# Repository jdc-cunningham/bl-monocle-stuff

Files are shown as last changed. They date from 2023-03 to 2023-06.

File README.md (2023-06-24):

### Desk stand for recording with phone

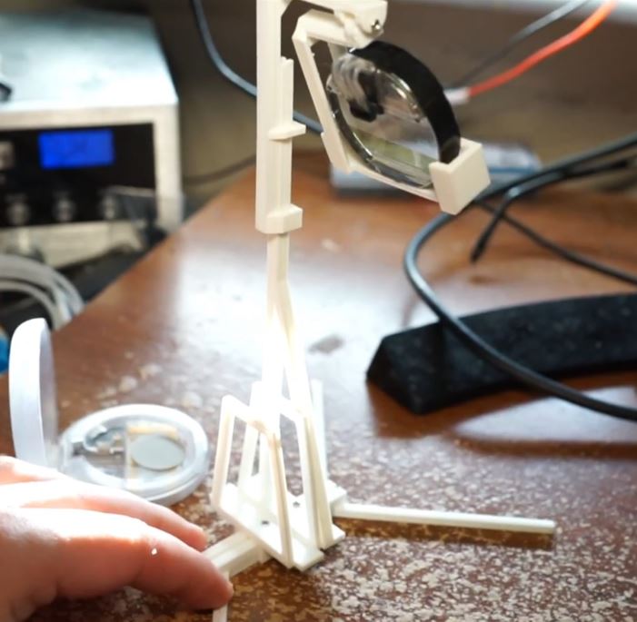
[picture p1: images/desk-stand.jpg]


This is designed to be dynamic for the most part (can fit different phones) with sliding adjustments

<a href="https://www.youtube.com/watch?v=oRKQFbEJR7w">View video (YouTube)</a>

### Hand held stand

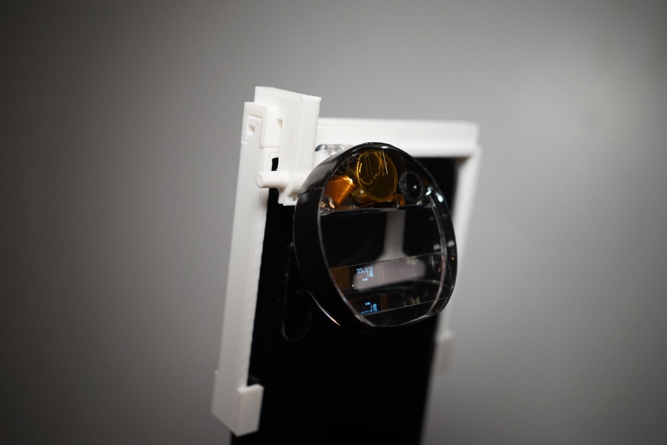
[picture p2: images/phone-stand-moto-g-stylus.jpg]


While this is custom designed for this phone (and one for iPhone 14 pro max), the concept is the same for other phones.

The simple design below can be used as a base regarding the paddle/rotating mechanism.

<a href="https://www.youtube.com/watch?v=hVtDwkcApw0">View video (YouTube)</a>

### "Popsicle stick" stand

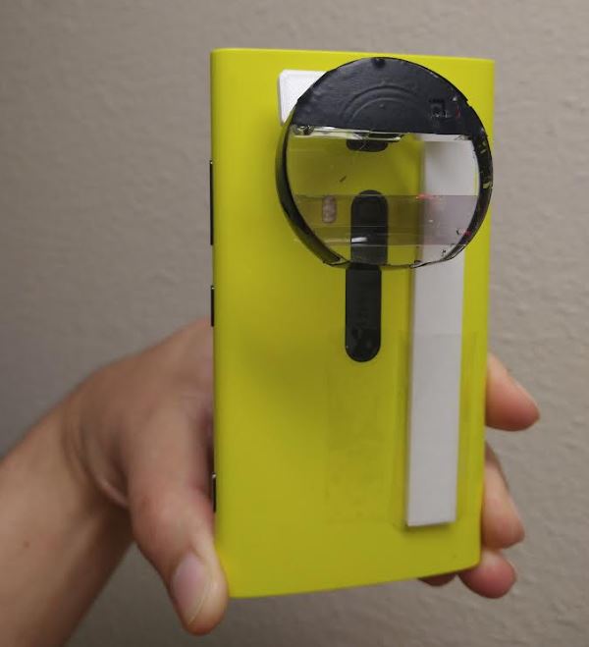
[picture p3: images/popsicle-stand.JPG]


This one is the simplest/fastest to print. It's nice because it be used for pretty much any phone. You can see here that I temporarily taped it to the phone.

### Permanent clip

This is a sign of madness

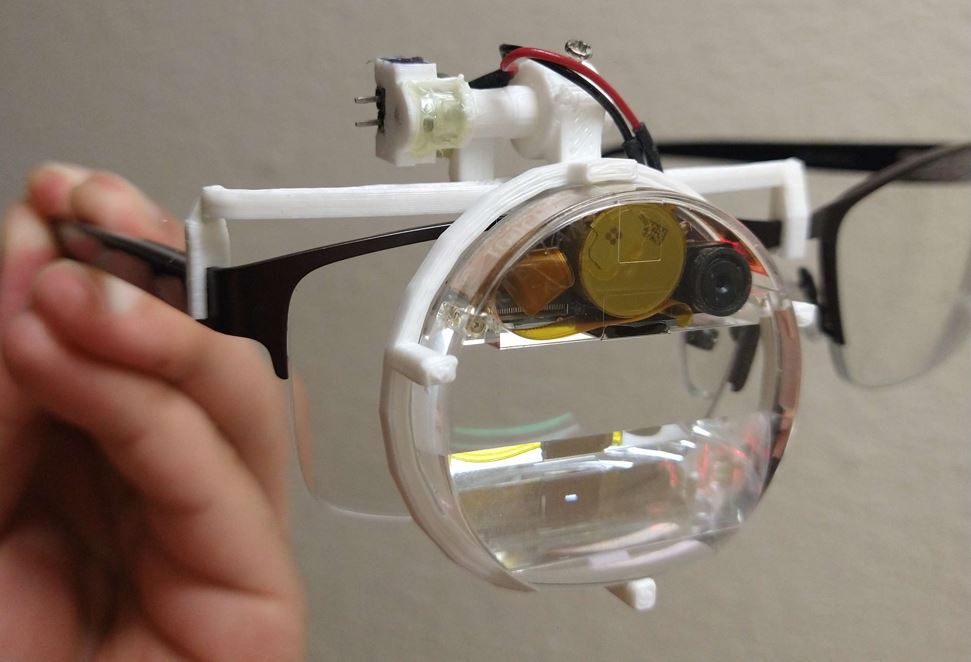
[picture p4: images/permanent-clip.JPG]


The point of this was so that I wouldn't have to take the monocle out of the case/position it over my eye just right every time I used it... During the process of prototyping many (~30) of these clips, I snapped the clip off. So I had to print the ring thing to hold it... anyway positive is I brought the image up/eye level vs. looking down (original) but the text is blurrier/farthest near corner text has doubling, redish tint in some areas near middle. It has a janky magnetic charger too.

Would I recommend? no

### Detachable clip (mod of above)

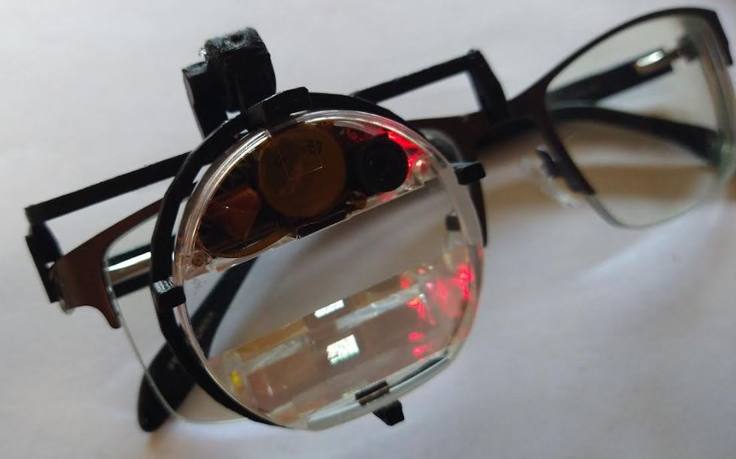
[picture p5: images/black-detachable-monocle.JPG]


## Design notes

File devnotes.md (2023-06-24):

06/24/2023

8:09 AM

just killing time, at this point I've switched to black fillament which is convenient, that looks better

I decided to not use the magnetic charging thing anymore, since the monocle does stop working after several hours of being on

Aside from that, it takes away from the original design where it was this thing that sits in a case/charges and you pull it out when needed

I unfortunately broke my clip off so that's why I'm using the clip design on my spare glasses

I did remove the soldered wires to the pogo contacts so it can go back into the case

The monocle no longer stays on as long as it can/back to normal use

I'm working on improving the clip design since it currently can fall out of the socket thing (monocle ring mount)

At least these are quick to print/try out and I have time to kill today

8:49 AM

the black filament looks good, more discrete

11:38 AM

the frame could be angled downwards more but I can compensate with "glue" (shudders) on the connection points, it looks great though in black

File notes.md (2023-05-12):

### Display text sizing

Currently can fit 26 across, 8 vertically eg. 8x26

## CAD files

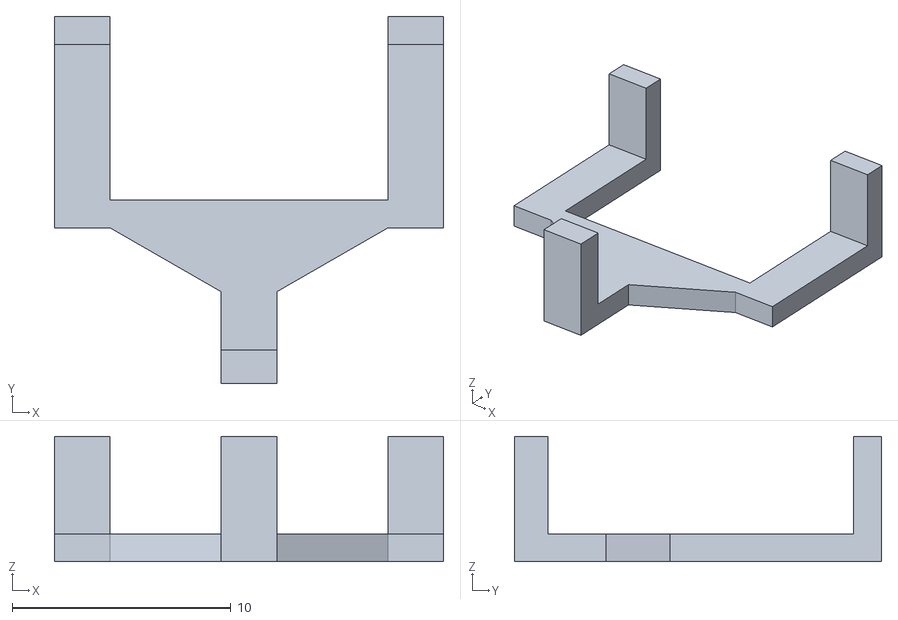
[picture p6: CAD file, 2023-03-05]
3d-printing/glasses-base-clip/base-clip.stl
17.8 x 16.8 x 5.72

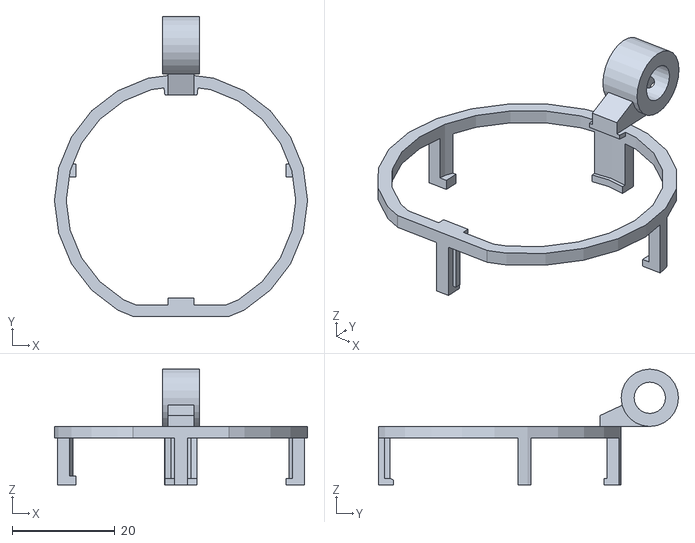
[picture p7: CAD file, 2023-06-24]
3d-printing/glasses-detachable-clip/monocle-ring-mount.stl
49.3 x 58.4 x 22.6

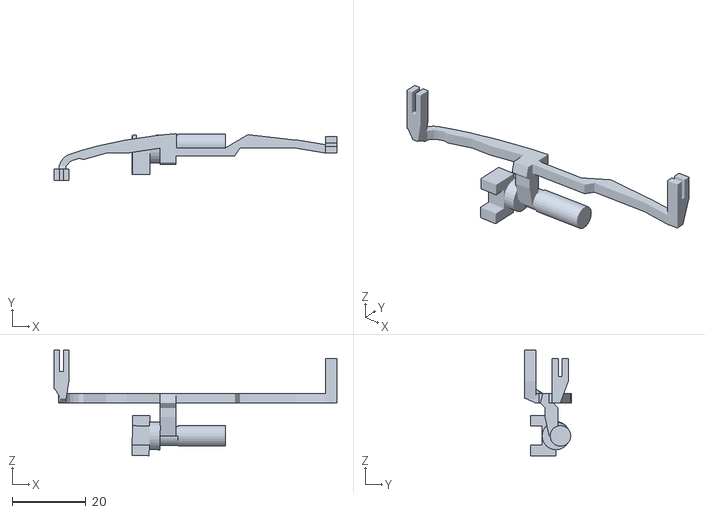
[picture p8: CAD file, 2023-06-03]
3d-printing/glasses-permanent-clip/clip.stl
76.6 x 12.6 x 28.6

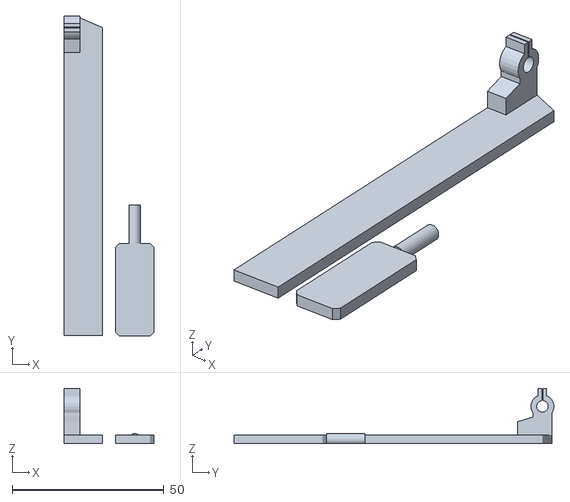
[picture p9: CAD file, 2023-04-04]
3d-printing/iphone-14-pro-max-pop-stick-mount/stick-and-roll-paddle.stl
29.7 x 105.5 x 18.2

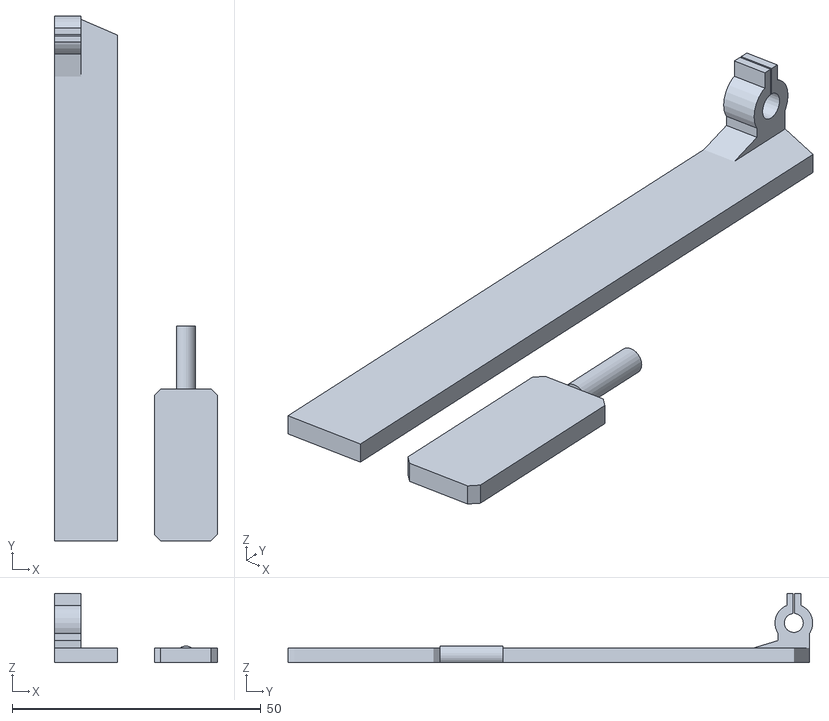
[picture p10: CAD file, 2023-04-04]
3d-printing/near-flat-cam-pop-stick-mount/pop-stick-mount.stl
32.8 x 105.4 x 13.9

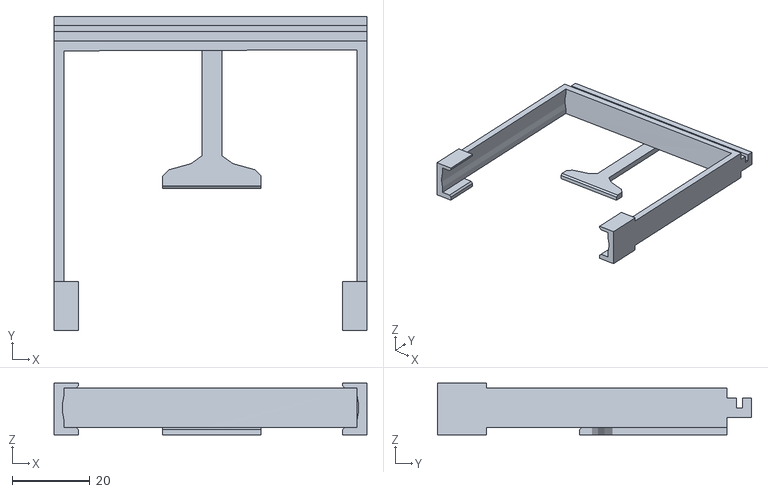
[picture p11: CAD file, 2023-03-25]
3d-printing/phone-hand-held-monocle-mount/stls/phone-clip-base.stl
80.7 x 81.0 x 13.3

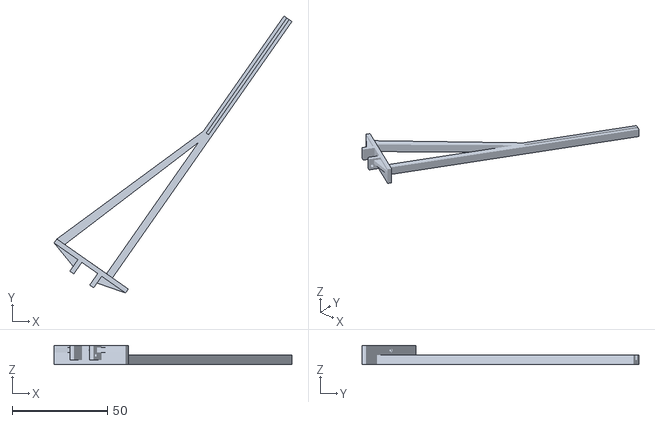
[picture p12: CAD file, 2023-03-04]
3d-printing/phone-recording-stand/stls/monocle-stand--hanger-sliding-shorter.stl
124.6 x 145.1 x 10.2

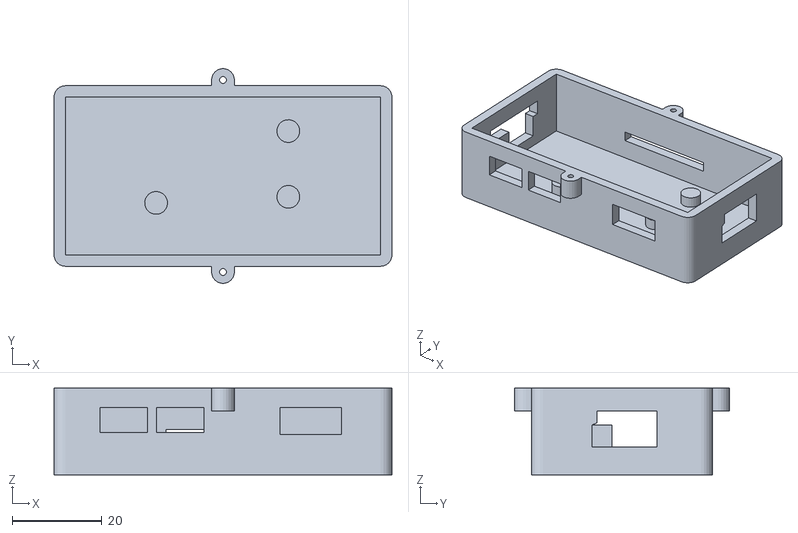
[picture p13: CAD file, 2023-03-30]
3d-printing/simone-pi-zero-case/print/pz-batt-case--bottom.stl
75.2 x 47.8 x 19.3

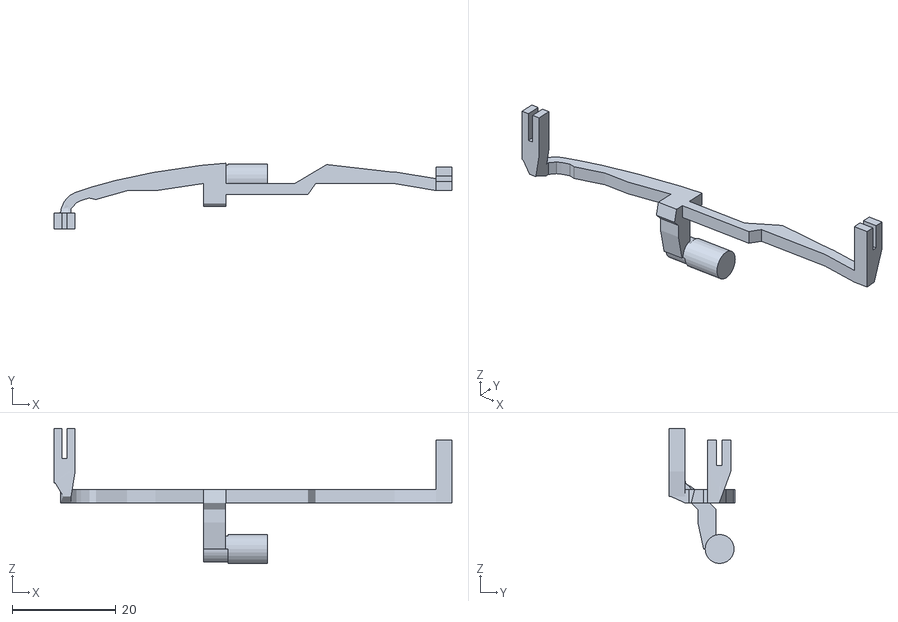
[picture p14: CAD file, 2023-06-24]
3d-printing/glasses-detachable-clip/clip.stl
76.6 x 12.6 x 26.0

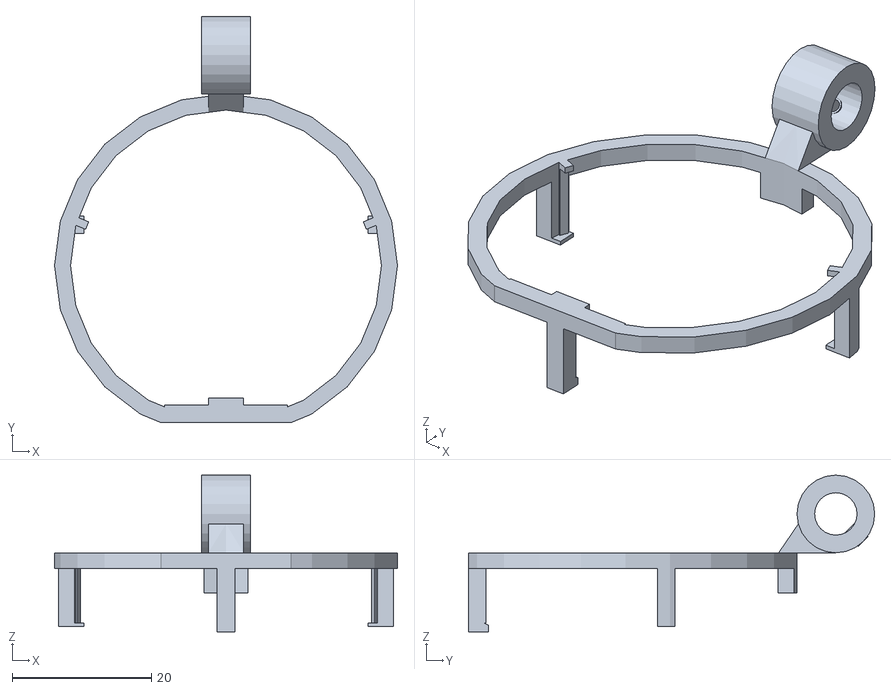
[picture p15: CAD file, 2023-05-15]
3d-printing/glasses-permanent-clip/monocle-ring-mount.stl
49.3 x 58.4 x 22.6

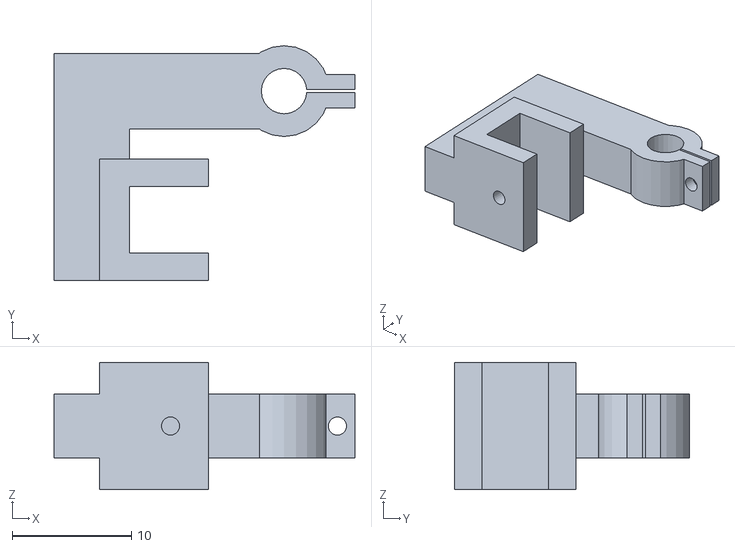
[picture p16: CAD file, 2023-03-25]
3d-printing/phone-hand-held-monocle-mount/stls/sliding-pincher.stl
25.3 x 19.7 x 10.7

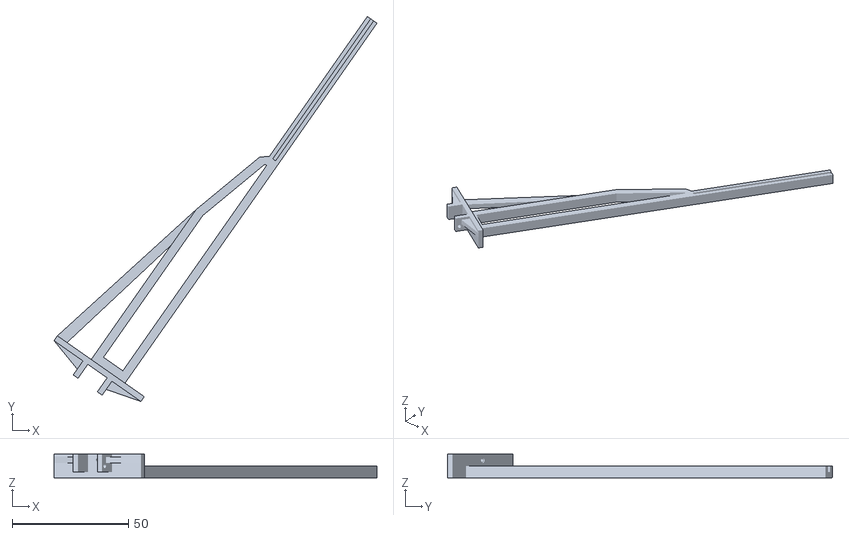
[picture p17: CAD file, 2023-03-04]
3d-printing/phone-recording-stand/stls/monocle-stand--hanger-sliding.stl
139.2 x 165.9 x 10.2

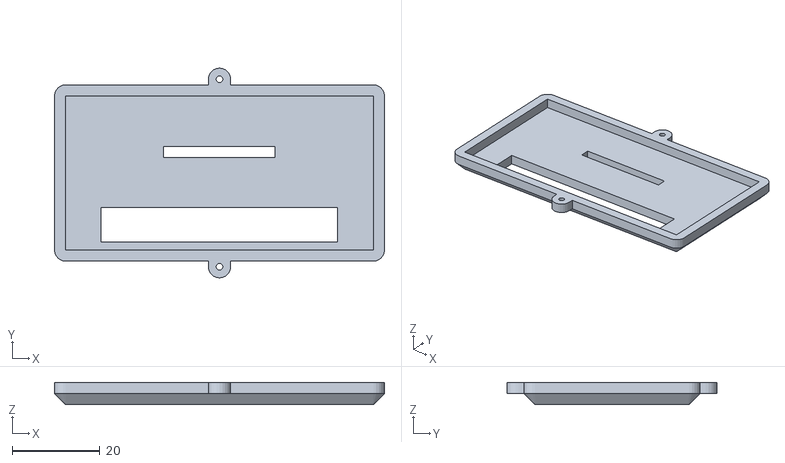
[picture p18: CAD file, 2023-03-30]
3d-printing/simone-pi-zero-case/print/pz-batt-case--top.stl
75.2 x 47.8 x 5.08

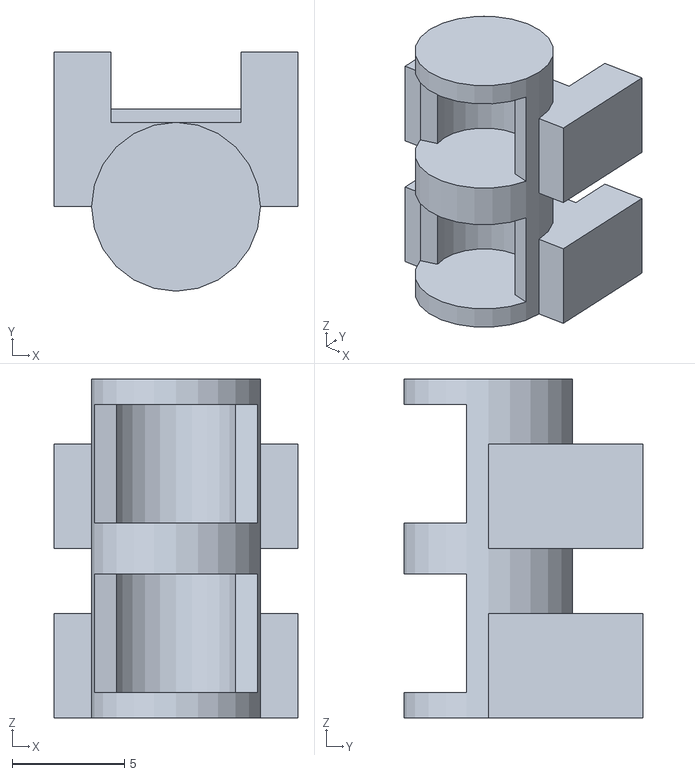
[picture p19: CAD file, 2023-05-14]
3d-printing/glasses-permanent-clip/Untitled-646140bf.stl
10.9 x 10.7 x 15.1

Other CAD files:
3d-printing/phone-hand-held-monocle-mount/stls/rotating-paddle.stl
3d-printing/phone-recording-stand/stls/monocle-sliding-pivot-mount.stl
3d-printing/simone-pi-zero-case/print/pz-batt-case--both.stl
3d-printing/glasses-permanent-clip/test-magnet-holder.stl
3d-printing/glasses-base-clip/base-clip.skp
3d-printing/glasses-detachable-clip/clip.skp
3d-printing/glasses-detachable-clip/monocle-ring-mount.skp
3d-printing/glasses-permanent-clip/2-pin-male-header.skp
3d-printing/glasses-permanent-clip/clip-0.skp
3d-printing/glasses-permanent-clip/clip-copy.skp
3d-printing/glasses-permanent-clip/clip.skp
3d-printing/glasses-permanent-clip/magnet-model.skp
3d-printing/glasses-permanent-clip/monocle-ring-mount.skp
3d-printing/glasses-permanent-clip/plug.skp
3d-printing/iphone-14-pro-max-pop-stick-mount/stick-and-roll-paddle.skp
3d-printing/models/monocle-mock.skp
3d-printing/models/moto-g.skp
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

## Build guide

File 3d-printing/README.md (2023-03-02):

### 3D Printing

The units are in inches

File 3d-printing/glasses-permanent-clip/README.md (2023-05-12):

### About

This one is so that I don't have to take the monocle out of the case/attach/reposition it on the monocle. Currently I don't take the monocle outside/just use it indoors when I cook food/wait for an hour every night.

So I'm going to make this work... then the monocle will just remain attached to my glasses in such a way that I can close the glasses arms and rest it on a thing and it'll charge.

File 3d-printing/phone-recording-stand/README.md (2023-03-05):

### Phone Recording Stand



The monocle is really hard to film IMO. It is best IMO to film it with your phone's macro feature.

So this is a stand that holds your phone upright/right against the monocle viewing area.

So you can record the monocle's display as you program it wirelessly via say the web repl.

Print times

- base 2hrs
- phone holder 40 mins
- hangar stand 1hr 47 mins
- monocle holder 1hr 9 mins
- video hangar 2 hrs (differnet height, vertically stacked cameras)

This stand was designed around 2020 Moto G Stylus

Using M1.7*6 screws

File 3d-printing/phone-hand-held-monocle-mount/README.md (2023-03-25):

### About



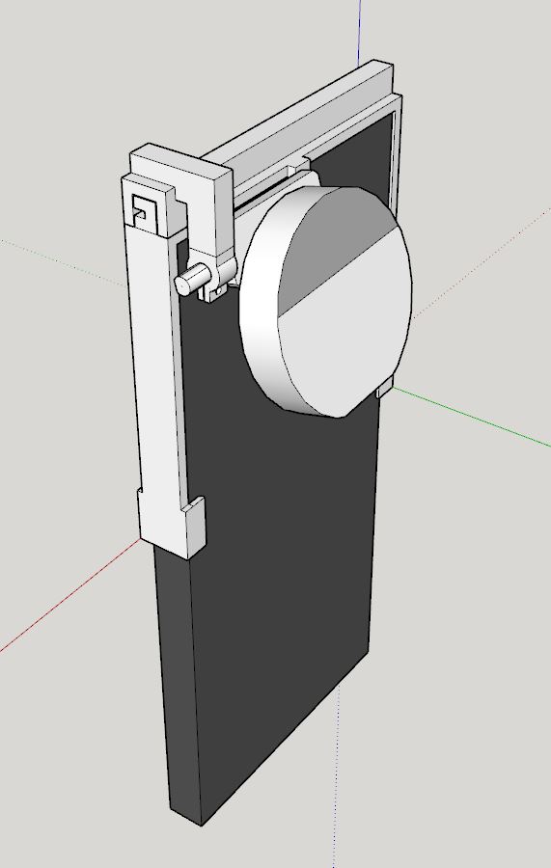
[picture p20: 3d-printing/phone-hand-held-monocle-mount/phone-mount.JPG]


This is a monocle stand that slides over your phone and allows you to record through the monocle as if being worn by an eye... specifically this one is mobile, it's not designed to be sat on a desk.

So if you want to record say an AR workflow with the monocle, you can use this.

Unfortunately phone designs vary and this one was designed around a Moto G although it has adjustable features.

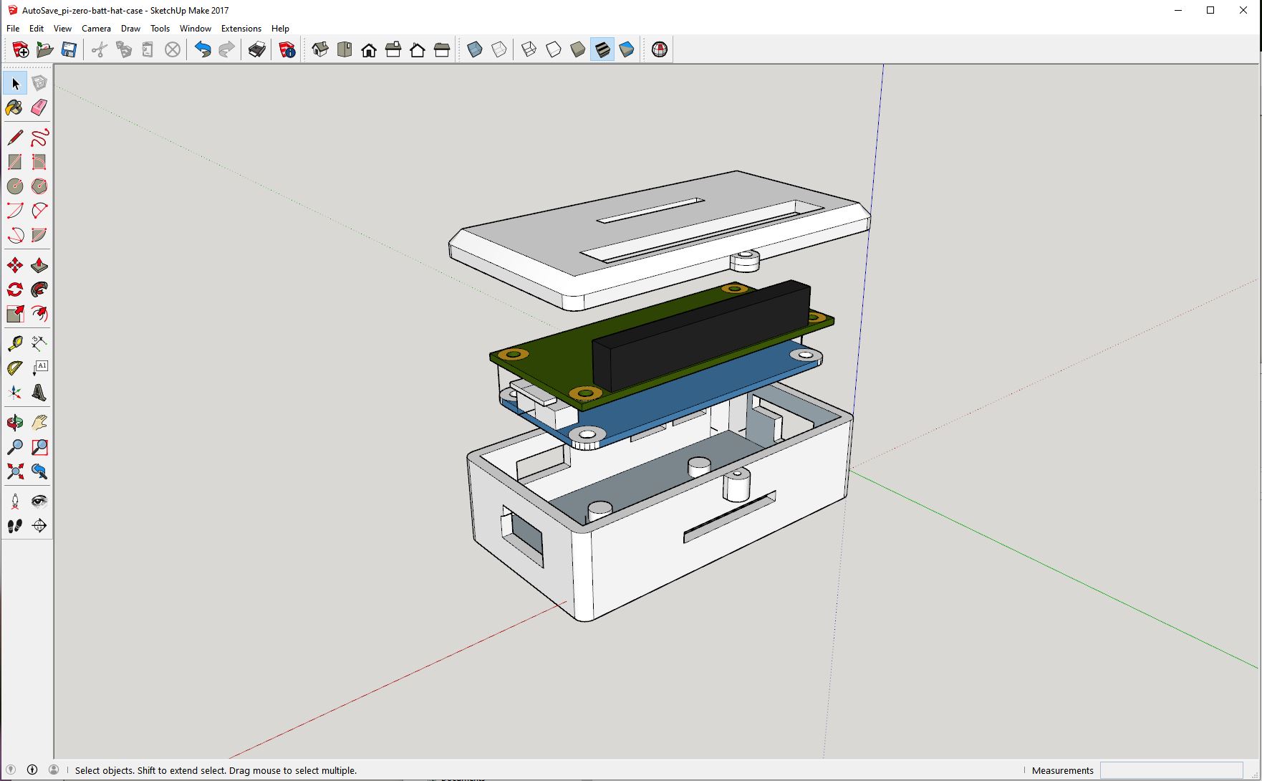
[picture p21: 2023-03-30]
3d-printing/simone-pi-zero-case/pi-zero-batt-hat-case.JPG

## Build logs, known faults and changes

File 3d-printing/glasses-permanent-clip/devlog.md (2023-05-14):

05/14/2023

2:07 PM

okay... I need to wrap this up, dropped 3 days on it

all just screwing around/printing... the TL;DR is if you move the lens up/you have to rotate it/move the thing farther away from your eyes = less crisp text/double vision/light red fading

so... it is best to just use it as is... but that's not great with regard to it being designed to look down towards the ground to use or to tilt your head up

so I will commit and see this through... use bigger text when it's available and also not use it as a teleprompter/way to read large blocks of text or use chunks of words

I have not done any work with the actual FPGA/CV stuff with this thing yet... just cool buzzwords on my part

I'm going to design the magnetic plug now

6:49 PM

broke the clip

making a round thing with swivel hole

05/13/2023

1:35 PM (woke up late)

still working on this... shifting back the monocle so it's not farther away and rotating in Z direction to focus the text edges

Not sure by how much, very little I think 1 degree to the right (brings right edge closer to eye)

11:02 PM

I am still tweaking/printing... I see to be going backwards and forwards

The issue is when you raise the monocle up higher in your FOV, you have to tilt it away from you... whihc you'd think geometrically it should be the same right?

Anwyay the problem is I'm either seeing white text turn a little pink in certain areas or there's double edges on text... and blurrier

The fix for some of that is changing color and increasing font size... also not to read a wall of text like a prompter

See all the revisions

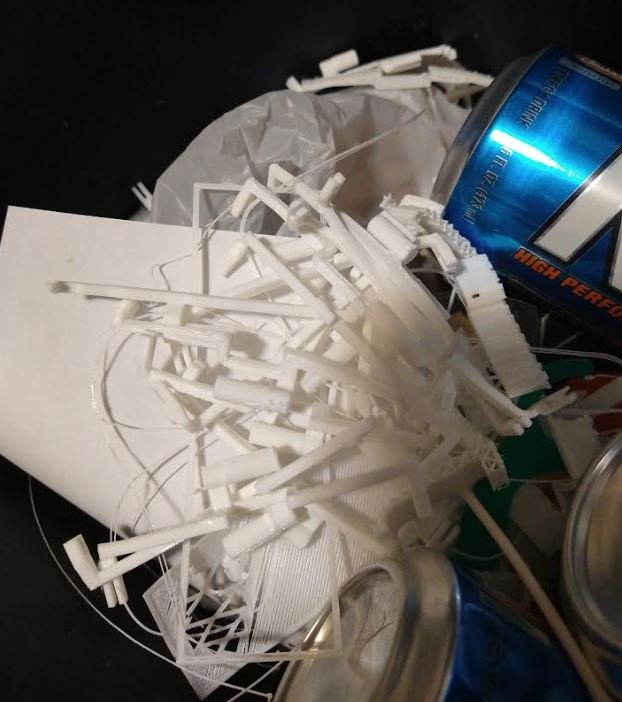
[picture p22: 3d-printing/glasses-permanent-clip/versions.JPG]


Each print started out about 20 some minutes, now they're between 39-41 minutes

I did design the magnetic connector but I have to finish it tomorrow once I settle on this glasses mount

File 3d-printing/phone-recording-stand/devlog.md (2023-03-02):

It would be an easier design/half print to have two parts.

One that holds the phone upright, the other one that holds the monocle upright... but also allows it to tilt.

Both have flat bases that can slide on a flat surface... that's how you would adjust it

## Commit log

2023-03-02 base design down
    [monocle-mock.skp, moto-g.skp, stand.skp]
2023-03-02 will print this on the weekend
    [stand.skp, stand.stl]
2023-03-02 need to redo it, do 2 separate parts
    [stand.skp]
2023-03-02 updated design
    [monocle-holder.skp, monocle-holder.stl, monocle-mock.skp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]
2023-03-02 missing a part
    [monocle-phone-holder.skp, monocle-phone-holder.stl]
2023-03-02 make stl
2023-03-03 add print itmes
    [monocle-stand--base.stl]
2023-03-04 add these files
    [monocle-sliding-pivot-mount.skp, monocle-sliding-pivot-mount.stl, monocle-stand--hanger-sliding.skp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]
2023-03-04 add shorter stand
    [monocle-stand--hanger-sliding-shorter.skp, monocle-stand--hanger-sliding-shorter.stl]
2023-03-05 doesn't stay on
    [base-clip.skp, base-clip.stl]
2023-03-24 start design of new mobile mount
    [phone-clip-base.skp, phone-clip-base.stl]
2023-03-24 quick save
    [phone-clip-base.skp, phone-clip-base.stl, rotating-paddle.skp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]
2023-03-30 design pi zero batt hat case
    [models.skp, pi-zero-batt-hat-case.skp, pi-zero-batt-hat-case__bottom-top.stl]
2023-03-30 separate parts
    [pz-batt-case--bottom.stl, pz-batt-case--top.stl]
2023-04-04 popsicle mount design
    [pop-stick-mount.skp, pop-stick-mount.stl, stick-and-roll-paddle.skp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]
2023-05-12 designing permanent clip
    [clip.skp]
2023-05-12 way too thin
    [clip-copy.skp, clip.skp, clip.stl]
2023-05-12 this is version 4 at this point, still making tweaks
    [clip.skp, clip.stl]
2023-05-13 still fine tuning
    [clip.skp, clip.stl]
2023-05-13 still not there
    [clip.skp, clip.stl]
2023-05-13 still going
    [clip.skp, clip.stl]
2023-05-13 have to move it backwards more, started on magnetic connector
    [clip.skp, plug.skp]
2023-05-14 this version is in the high 20's at this point dang
    [clip.skp, clip.stl]
2023-05-14 working magnet charge
    [2-pin-male-header.skp, Untitled-646140bf.stl, clip-0.skp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]
2023-06-02 undoing, lower profile, match original design
    [clip.skp, clip.stl]
2023-06-03 final design
    [clip.skp, clip.stl]
2023-06-24 updating design, back to case charging
    [clip.skp, clip.stl, monocle-ring-mount.skp]
